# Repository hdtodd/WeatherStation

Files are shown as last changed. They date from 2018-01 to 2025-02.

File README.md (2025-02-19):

# WeatherStation/WeatherProbe v5.3
### A Raspberry Pi Weather Datalogger with </br>Arduino WeatherProbe Data Collector 

**Written by David Todd (hdtodd@gmail.com) </br>
August 2015-December 2022, Bozeman MT/Williston VT**

This project implements a weather data logging system comprised of:

1.  a Raspberry Pi program to collect meteorological data from an attached Arduino probe and 
store the data in a MySQL or sqlite3 database, or print out as simple labeled data fields, or print out or store as XML-formatted data;

2.  an Arduino Uno program to collect the meterological data from connected devices and present the data for viewing or storing.  The following devices are supported but optional.  None are required for operation -- the Uno program samples and displays data from only the devices that are attached and ignores missing devices.
  * MPL3115A altimeter/barometric pressure/temperature sensor
  * DHT22 temperature/relative humidity sensor
  * DS18-class temperature probes (zero or multiple)
  * Chronodot real-time clock
  * A 1.8" TFT color LCD display.

4.  A `Makefile`to create and install the Raspberry Pi code, including a `systemctl WeatherStation.service` file for automatic operation upon reboot;

5.  Web service support with PHP and Python code examples used with an Apache server to create web-page graphical displays using Google Charts

6.  XML DTD file and XML file parser to validate the XML data file and extract data from a validated, conforming XML file.

The Arduino is connected to the Pi or other Linux system (or Mac OSX) via USB cable.  The supplied Arduino code
is compiled on the Pi or OSX and downloaded over USB cable to the Uno (which also receives its power from the USB cable).  The WeatherStation program operating on the Pi or OSX issues commands to the Uno and receives data in return, which is then displayed to the user or stored in a database.

The included PHP and Python files offer prototypes for displaying data collected in the database (in sqlite3 format in this case) and/or presenting via an Apache2 server.

This distribution includes the source code for WeatherStation (Pi) and WeatherProbe (Arduino), Makefiles, installation guide, principles-of-operation manual, and circuit diagrams.

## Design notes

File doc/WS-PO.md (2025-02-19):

# WeatherProbe/WeatherStation</br>Principles of Operation
### H. David Todd, hdtodd@gmail.com, January, 2018

**WeatherProbe** (WP) is a program that runs on the Arduino single-board microcontroller to manage and read data from various meterological sensors.

**WeatherStation** (WS) is a program that runs on the Raspberry Pi or other Linux/Macintosh system to store that meterological data and report or present it.

They are the Arduino and Raspberry Pi software components, respectively, of a meterological station **system**. They work together to collect+display (Arudino) and record+present (Pi) meterological data from a set of sensors connected to the Arduino. This document describes the operation of that system -- how the individual components function and how they function as a system.  This PO manual may help others add components to the Arduino or functionality to the system.

## Basic Operation

### System Data Flow
The WS program on the Raspberry Pi/Linux controller manages the WP probe program on the Arduino over the USB serial port that connects the two (and powers the Arduino).  In response to commands coming over the USB serial port from WS on the Pi, the WP program performs actions, including sampling of data from its sensors, and reports the results via the USB serial connection back to the WS program if it has been commanded to do so.  

The WS program then performs the reporting action *it* was commanded to do at startup.  WS reporting options include:

1. Reporting results on the terminal controlling the WS program, in a report format with well-formatted lines and with labels for data;
1. Appending the results to a sqlite3 (default) or MySQL database;
1. Appending the results to an XML file, with appropriate XML tags in conformance with a standard DTD template for the reported data.

Operating independently, an Apache web page with PHP code can be used to access the sqlite3 or MySQL database to show current meteorologial conditions and display graphically a history (default 1 week) of temperature and pressure.  

The WP program primarily performs actions only in response to WS commands over the USB serial port.  The exception is that it periodically (default 1 minute) samples the sensors and updates the TFT display, if there is one, with current conditions.

## WeatherProbe (WP -- Arudino Code)

Arduino code has two major procedures as the main program: setup() and loop().  One-time initialization tasks are performed in setup(), and the program then enters loop(), which executes repeatedly until powerdown or restart.

### Startup
Upon upload, powerup, or restart, the WP code in the setup() procedure in the Aruindo:

1. Initializes the USB Serial port (default 9600 baud)
1. Attempts to verify active electrical connections to the TFT LCD display, the real-time-clock, and then to each of the sensors for which it has support code.  It marks as absent those devices that don't respond or don't respond correctly during this setup phase, and no further attempt is made to communicate with them.  
1. Announces its presence over the USB Serial port.
1. Enters a loop in which it continuously performs the following steps.
	1. Periodically (default 1 minute) updates weather information on the TFT display attached to the Arduino, if there is one.
	1. Looks for a command string coming over the USB serial port from the controlling device or person.
	1. In response to commands, performs the appropriate action, perhaps with text response back to the controlling device/person over the USB serial port.  The most common command operation would be `sample`, which causes WP to sample the data from each of the sensors; update the display (if there is one); and, if it has been requested to do so, report the sampled data with date-time stamp in the appropriate format (report, CSV, or XML).
	1. Repeat the loop to await further commands, while continuing to update the display periodically, if there is one. 

There is no "exit" from this code.  Once it has initialized in setup(), it enters the loop() procedure and loops until it receives a command to `restart`, at which point it simply restarts the process from step 1 above, or until the Arduino is reloaded or powered down.

### Device Support on the Arduino
WP has support for the following devices connected to the Arduino:

1. Chronodot real-time-clock, connected via I2C 
1. SainSmart 1.8" TFT LCD Display connected via SPI
1. MPL3115A2 altitude/barometer/thermometer sensor connected via Arduino pins
1. DHT22 temperature/humidity sensor connected via Arduino pins
1. DS18-class thermal sensors (up to 4, as a compile-time parameter) connected via OneWire interface to Arduino pins

If a Chronodot is not present, WP uses the internal clock of the Arduino to timestamp events.  That clock can be set by command from the controlling host over the USB serial line, which WeatherStation does when it starts up.  You'll need to do that manually if you're running WP in terminal monitor mode.

If a TFT display is present, it is used to show the date-time stamp of the latest sample, the temperatures reported on the first two DS18 temperature probes in that sampling, the relative humidity, and the **unadjusted** (see MPL below) barometric pressure in Pascals (divide by 100 to get millibars). **Barometric pressure is adjusted by the MPL3115A2 code for the altitude of the device, which is a compile-time parameter set at 40m.  It is otherwise reported from the raw data read and not adjusted for temperature or humidity.** 

If any of the other devices is absent or not sensed correctly, its absence is reported at startup over the USB serial port and it is marked absent internally.  No further attempt is made to gather data from that device, and any reported values are reported as zeros.

### WP Commands
Command processing within WP is very restricted.  The command processor does not handle line editing such as backspace character deletion or line deletion.  Input that is not recognized as a correctly-formed command is discarded: the complete line is ignored, no action is taken, and a prompt is sent over the USB serial line to indicate the commands WP is prepared to process (equivalent to having sent a "?" or "help" command).

WP commands include the following set:

*  **help** or **?** or simply **\<CR\>** (blank line)</br>returns a string over the USB serial connection to the controlling program/terminal with this list of its commands

*  **version** or **whoru**</br>returns a string identifying the version of WP and of the database for which WP is providing data (number of sensor readings and sequence of returned values must correlate with what the controlling program is expecting to store in its database)

*  **report**</br> sets WP to be in *report* mode so that subsequent `sample` commands return the timestamped, collected sensor-data string as a formatted line of labeled data

*  **csv**</br>sets WP to be in *csv* mode so that subsequent sample> commands return the timestamped, collected sensor-data string in comma-separated-variable format.  As compiled, the string has the format "(val,val,val, ...)" [see Reports, below].

*  **xmlstart**</br>causes WP to immediately return the XML header string over the USB serial port and then sets WP to be in *xml* reporting mode so that subsequent sample commands return the timestamped, collected sensor-data as XML-tagged data samples.

*  **xmlstop**</br>causes WP to immediately return the XML termination string over the USB serial port and disable xml reporting mode (reporting is disabled until another command is issued that again enables a reporting mode)

*  **sample**</br>causes WP to sample each of the known sensors and update the TFT display, if there is one.  If a reporting mode is enabled, WP also returns, over the USB serial connection to the controlling program/terminal, a string containing the date-time stamp and sampled data in the format required by the active reporting mode.</br></br>With a full set of devices, the time required for one sampling is about 1400 milliseconds (1.4 sec).

*  **settime yyyy-mn-dd hh:mm:ss** (all digits, 24-hour clock, must be formatted exactly in this way) causes WP to set the Chrondot real-time clock (if there is one) or the date-time offset for the internal Arduino interval timer, so that subsequent date-time stamps are synchronized with the host computer system.

*  **restart**</br>causes the Arduino to reboot and restart WP.

### WP Device Details

Most of the devices supported by WP are straightforward: one device, one connection, one set of data per sampling.  The exception is the DS18-class thermal sensors connected via OneWire: there may be many DS18 devices (limit of 4 as compiled).

#### **Chronodot RTC**
The Chronodot is a battery-maintained real-time-clock (RTC) that provides the date-time string used as timestamp for data records sent to the controlling program/terminal and used to display on the TFT display (if there is one).  Other RTC devices could be substituted for the Chronodot with minor changes to the code in WP.  WP assumes that the Chronodot date+time have been set before WP starts up, but the Chronodot's time can be changed with the `settime` command.  In the absence of a Chronodot, WP uses the the elapsed time since WP started as the current date+time for its date-time stamp, but, again, its base time can be set with the `settime` command.
#### **TFT Display**
The SainSmart 1.8" TFT LCD display is a color 128x160-pixel display connected via SPI interface.  The SainSmart version differs from the Adafruit version in its pinouts.  The implementation here (ST7335) uses the SainSmart pin layout for "high display speed" [[https://www.tweaking4all.com/hardware/arduino/sainsmart-arduino-color-display/]()].  WP supports the ST7735R and  ILI9163C models. The WP code is compiled to display in portrait mode but could be easily modified for landscape. The code is highly modular, with display initialization in separate section within setup() and with the display code itself in a separate procedure called from within loop().  
#### **MPL3115A2**
The MPL3115A2 is a sophisticated altitude/barometer/temperature sensor that provides the ability to read each type of sensor data independently.  Internally, the MPL reads pressure relative to an internal vacuum chamber.  It provides the ability to add a "trim" to pressure and altitude readings to compensate for any internal inaccuracies.  In setup(), WP sets that "trim" value for altitude to the difference between the MPL-measured value and a reading you might make from a GPS system, and the MPL applies that trim to any altitude reading it makes.  (The MPL code does not provide for applying pressure "trim").  Set `MY_ALTITUDE` in `WP.h` to your GPS-measured altitude, in meters, if the altitude reading is important to you and you intend to move the location of the Arduino probe with its MPL.  During sampling, WP collects altitude, pressure, and temperature from the sensor.  Using a terminal connection, put WP in `report` mode and command a `sample` to obtain the MPL readings for all three sensor values.</br>
#### **DHT22**
The DHT22 device senses temperature and relative humidity.  No settings or adjustments are possible.  During sampling, WP simply requests current values for temperature and relative humidity.  A DHT11 or DHT21 device may also be used (compile-time parameter).
#### **DS18B20**
The DS18B20 is one specific example of the OneWire DS18-class thermal sensors, and it is the device with which WP was developed.  WP *should* support the other DS18 devices (DS18S20, DS1822, DS18B20) with no code changes or recompilation required, but it should be validated with other devices before putting into production.

WP samples the two-character DS18 device label along with the temperature and reports those pairs for all connected devices to the controlling program or terminal.  WP assumes that the 2-byte Tl/Th (low/high temperature trigger settings) that are stored in DS18 EEPROM are two-character labels. (The DS18 github distribution includes a DS18 labeling program, but two bytes of the OneWire address might be used as an alternative, with minor coding changes, with some chance that labels wouldn't be unique).  Absent devices are reported as a (label,temp) pair value of ('\*\*',0.0)</br></br>By default, temperatures are measured with 10-bit precision to 0.25C (compilation parameter).</br></br>WP uses the  concurrent-sampling capability of the DS18 device: sampling is initiated concurrently across *all* DS18's, data is collected from other sensors, and then data is collected from the DS18's.  This sampling parallelism speeds up the sampling loop considerably if multiple DS18s are attached.  **As a result, the DS18's must be connected to VCC for power and cannot operate in parasitic mode.**

### WP Report Strings
WP reports sample results, if commanded to do so, as either line-printer style reports (labeled data values), csv-formatted lines (no labels), or as XML-formatted data.
#### **report**
Samples are reported as one line returned with labeled data in the format:
```
2017-09-18 16:46:59  MPL: Altitude=1650.9m Pressure=83661Pa Temp=69.8F  DHT22: Temp=70.5F @ 35% RH  DS18: IN=70.7F OU=58.1F **=0.0°F **=0.0°F 
```
DS18 labels for missing devices (in the list of 4 maximum) are given as `**` and the corresponding temperatures are `00.0`.

#### **csv**
Samples are reported as one line returned in the format "(val,val,val, ...)", with the following values in this sequence and format:

1. 'date-time' (in quotes),  in the format `'2017-09-18 16:22:05'`, suitable for reading as a string and passing to sqlite3 or MySQL
2. MPL3115A2 pressure, integer in Pascals
3. MPL3115A2 temperature reading, float in Fahrenheit
4. DHT22 temperature reading, float in Fahrenheit
5. DHT22 relative humidity reading, integer in %
6. #1 DS18 label, in the format 'xx' (in quotes)
7. #1 DS18 temperature reading, float in Fahrenheit
8. #2 DS18 label, in the format 'xx' (in quotes)
9. #2 DS18 temperature reading, float in Fahrenheit
10. #3 DS18 label, in the format 'xx' (in quotes)
11. #3 DS18 temperature reading, float in Fahrenheit
12. #4 DS18 label, in the format 'xx' (in quotes)
13. #4 DS18 temperature reading, float in Fahrenheit

#### **xml**
Sample data, in the order listed for `csv`, are reported in conformance with the XML DTD template provided with the source code (weather_data.dtd: see [Appendix](appendix-0) ).  Each sampling is marked by a \<sample\>\</sample\> begin-end pair and includes the date-time stamp and all available data in the sample, labeled and with units specified.</br>

### WP Error Processing
The WP code compiles to nearly 32K, and there is little room for additional functionality or error detection.  Attempts are made to report most errors that can WP detect, but the code is not "bullet proof".  Error and warning messages are sent over the USB serial line:

*  Informational and warning messages are preceeded by the text string "[%WP]""
*  Error messages indicating failures are preceeded by the text string "[?WP]""

A program controlling the Arduino running WP via the USB serial port can use these leading text string to identify messages that should be sent to a controlling terminal screen and/or logged to an error file.

## WeatherStation (WS -- Raspberry Pi/Linux Code)

The WS program executes on a Raspberry Pi or other Linux/Mac OSX system to collect and record data from the Arduino weather probe program, WP, over the USB serial connection between the Pi and and Arduino.

### Startup

WS starts by: 

*  processing command-line arguments (see below); 
*  verifying that it can access database files, if needed;
*  verifying that there is an Arduino connected to the Raspberry Pi with which it can communicate;
*  issuing the appropriate command to the Arduino needed to obtain data in the format that has been requested.

WS then enters a loop in which it commands the Arudino to sample data from the Arduino's sensors, receives the sample data in reply, records or prints that data as requested, then delays (default 5 minutes) before repeating.  This continues until the program is terminated.

### WS Device Support

WS was designed to connect to a single Arduino Uno via USB serial port, and it was tested only in that mode.  However, other modes of operation should be possible with relatively minor modifications or additions to the WS code:

*  Serial connection might be made by other means, such as Bluetooth Serial or WiFi or Pi/Arduino serial ports.  A wireless connection to a remote Arduino would be one of the more interesting and useful approaches and should be relatively easy to implement.
*  Multiple Arduinos could be supported from one instance of WS, or by running multiple instances, each connecting through different serial connections to different Arduinos.

### WS Commands

WS is not an interactive program.  It accepts one of three commands on the command line at startup and continues operation until terminated: 

*  `ws prt`, to indicate that WS should generate report-style printouts to the controlling terminal;
*  `ws sql`, to indicate that WS should append sample data to the database file (either sqlite3 or MySQL, depending upon compilation parameters); or 
*  `ws xml` or `ws xml filename` to indicate that WS should write data in XML format to either the controlling terminal or to the file specified as `filename`.

Any other argument on the command line, or no argument on the command line, results in a "help" response that shows what `ws` does and what it is expecting on the command line.  Any additional arguments on the command line are ignored (though redirects for `stdout` and `stderr` work as expected).

WS can be terminated with a CNTL-C (^C) from the controlling terminal or stopped with the command</br> 
`sudo systemctl stop WeatherStation.service` 
</br>if WS is operating as a `systemd` service.  As a result, the XML file is properly closed with `</sample>` under normal circumstances (but check and append that closing string to the .xml file if the system has crashed in a power failure).

### WS Databases

WS can record the date-time stamped sample data it receives from WP in either a sqlite3 (default) or MySQL database.

#### **sqlite3 Database Operations**

The sqlite3 database file name, by default in the code, is `~/WeatherData.db` so that it can be created and written to by the user during initial testing.   But in Makefile, that definition is overridden and the database filename is set to be `/var/databases/WeatherData.db` so that the system is set up for production operation.  **Note that that file will normally be protected, so either WS must run as root (or as a systemd service) or the file must be created and protections set to enable writing by the user.**

On startup, if the sqlite3 database *file* `/var/databases/WeatherData.db` doesn't exist, WS creates it.  The sqlite3 code uses a table named `Probedata` in that database file.  If it doesn't exist in the file, WS creates it with the command:

	CREATE TABLE if not exists ProbeData (date_time TEXT PRIMARY KEY,
	mpl_press INT, mpl_temp REAL, dht22_temp REAL, dht22_rh INT,
	ds18_1_lbl TEXT, ds18_1_temp REAL, ds18_2_lbl TEXT, 
	ds18_2_temp, REAL,ds18_3_lbl TEXT, ds18_3_temp REAL,
	ds18_4_lbl TEXT, ds18_4_temp REAL)

During operation, WS receives sample data from WP over the USB serial port in CSV format, with data in the order and of the types indicated in the `CREATE TABLE` command above.  It appends the received data to the sqlite3 database file with the command:

	INSERT INTO ProbeData (date_time, mpl_press, mpl_temp, dht22_temp, dht22_rh,
	ds18_1_lbl, ds18_1_temp,ds18_2_lbl, ds18_2_temp,ds18_3_lbl, ds18_3_temp,
	ds18_4_lbl, ds18_4_temp) VALUES (val, val, val, ...)
	
where the `VALUES` list is a direct copy of the string sent by WP in response to a `sample` command while in CSV mode.

The sqlite3 database file is opened and then immediately closed when recording each individual sampling, so that the file is minimally vulnerable to corruption in case of system crash.

The sqlite3 database can be examined as a normal sqlite3 database table, for example, with the command:

	$sqlite3 /var/databases/WeatherData.db
	sqlite> select * from Probedata where date_time > datetime('now', '-4 hours');
	...
	2017-09-19 08:06:57|83808|65.9|66.7|40|IN|70.3|OU|36.5|**|0.0|**|0.0
	2017-09-19 08:12:07|83813|65.6|66.4|37|IN|69.8|OU|36.0|**|0.0|**|0.0
	sqlite> .quit

WS can use a MySQL database to store its sampled data, too: see the WS-WP-install.md file for compilation instructions.

Operation of WS using a MySQL is very similar to its operation using sqlite3.  However:

*  mysql server must be running (generally done as a startup service, likely with systemctl)
*  username and password for a MySQL account that can append to the database must have been provided (edit WS.h, `make clean` and recompile with `USE_MYSQL=1 make`)
*  A `weather` database and `Probedata` table in that database must have been created under that user account with the correct field names and data types, per installation instructions.

Create the database and table with the command:
	
	$mysql -u <username here> -p
	<provide password here>
	create database weather;
	use weather;
	CREATE TABLE `ProbeData` (
  		`date_time` datetime NOT NULL,
		`mpl_press` int(6) unsigned NOT NULL,
  		`mpl_temp` float NOT NULL,
  		`dht22_temp` float NOT NULL,
  		`dht22_rh` smallint(5) unsigned NOT NULL,
  		`ds18_1_lbl` char(2) COLLATE ascii_bin DEFAULT NULL,
  		`ds18_1_temp` float DEFAULT NULL,
  		`ds18_2_lbl` char(2) COLLATE ascii_bin DEFAULT NULL,
  		`ds18_2_temp` float DEFAULT NULL,
  		`ds18_3_lbl` char(2) COLLATE ascii_bin DEFAULT NULL,
  		`ds18_3_temp` float DEFAULT NULL,
  		`ds18_4_lbl` char(2) COLLATE ascii_bin DEFAULT NULL,
  		`ds18_4_temp` float DEFAULT NULL,
  		UNIQUE KEY `date_time` (`date_time`)
		);
	show columns from ProbeData;
	quit;

In operation, WS again opens and closes database access just to record data: the connection to the database is not kept open during operation.

### WS Error Processing

There is limited error handling in WP, but WS reports the errors that occur in its side of the processing and forwards the error messages it receives from WP.  Nevertheless, the code is not "bullet proof", particularly with regard to errors that might occur in the communication between the Raspberry Pi and the Arduino.  However, the USB serial connection appears to be very stable and reliable, running for months at a time without disruption.

Similar to error messaging in WP, WS error messages have the following formats:

*  Informational and warning messages are preceeded by the text string `"[%WS]"`
*  Error messages indicating failures are preceeded by the text string `"[?WS]"`

Informational messages from WS are printed to `stdout` (the connected terminal).

Informational messages from WP and error messages from both WS and WP are printed to `stderr` by WS.  These will normally be printed to the connected terminal but can be redirected to error logging files, for example with the command:

	$./ws sql 2>wserrors.log

## Appendix:  weather_data.dtd
The listing below is the DTD template to which the WP xml output conforms.  XML output files can be validated or converted to CSV format with tools supplied with the WS/WP source code.

	<!ELEMENT samples (sample*)>
	<!ELEMENT sample (source_loc?, date_time, MPL3115A2?, DHT22?, DS18*) >
	<!ELEMENT source_loc (#PCDATA) >
	<!ELEMENT date_time (#PCDATA) >
	<!ELEMENT MPL3115A2 (mpl_alt?, mpl_press, mpl_temp) >
  		<!ELEMENT mpl_alt (#PCDATA)>
     		<!ATTLIST mpl_alt
        		alt_unit (ft|m) "m">
  		<!ELEMENT mpl_press (#PCDATA) >
     		<!ATTLIST mpl_press
				p_unit (Pa|mb|inHg) "Pa" >
  		<!ELEMENT mpl_temp (#PCDATA) >
     		<!ATTLIST mpl_temp
				t_scale (C|F|K) "F">
	<!ELEMENT DHT22 (dht_temp, dht_rh) >
   		<!ELEMENT dht_temp (#PCDATA) >
     		<!ATTLIST dht_temp
				t_scale (C|F|K) "F">
   		<!ELEMENT dht_rh (#PCDATA) >
     		<!ATTLIST dht_rh
				unit CDATA #IMPLIED>
	<!ELEMENT DS18 (ds18_lbl, ds18_temp) >
   		<!ELEMENT ds18_lbl (#PCDATA) >
   		<!ELEMENT ds18_temp (#PCDATA) >
     		<!ATTLIST ds18_temp
        		t_scale (C|F|K) "F">

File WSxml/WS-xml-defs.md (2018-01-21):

#WeatherStation XML Data Definitions

The file "weather_data.dtd" contains the definitions of the data elements that the parser is prepared to process and extract/report.  Examining the .dtd file, even without experience in xml DTD definitions, will help understand how to make changes or additions.  Here's a simple guide to the format of the .xml file.

* A conforming .xml file will begin and end with \<samples> and \</samples>
* Between those, the file may contain 0 or more elements marked with \<sample> at the beginning of the entry and \</sample> at the end.  These elements contain the data associated with one sampling of the sensors from which the probe is collecting data.
* A *sample* may contain zero or one \<source_loc> element with a text value.
* A *sample* **must** contain just one \<date_time> element with a text value.
* A *sample* may contain zero or one \<MPL3115A2> element with several required components:
	* \<mpl\_alt> or \<mpl\_alt alt\_unit=ft|m>, with a text value (note that "ft|m" means to put **either** ft or m as the unit of measure; same approach in other unit settings; in this case the measure is feet or meters, ft or m)
	* \<mpl\_press> or \<mpl\_press p\_unit=Pa|mb|inHg>, as text, units being Pascals, millibars, or inches of mercury
	* \<mpl\_temp> or \<mpl\_temp t\_scale=C|F|K>, with temperature value in text and units being Centigrade, Farenheit, or Kelvin
* A *sample* may contain zero or one \<DHT22> element, each with two required components:
	* \<dht\_temp> or \<dht\_temp t\_tscale=C|F|K> with temperature value as text
	* \<dht\_rh> as text representing the relative humidity in percent (%)
* A *sample* may contain zero or more \<DS18> elements, each with two required components:
	* \<ds18\_lbl> as text representing the two-character DS18 internal label
	* \<ds18\_temp> or \<ds18\_temp t_scale=C|F|K> with temperature value as text

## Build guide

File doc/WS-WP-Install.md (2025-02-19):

# WeatherProbe/WeatherStation</br>Installation Guide

**WeatherProbe** (WP) is a program that runs on the Arduino single-board microcontroller to read data from various meterological sensors and display current conditions on a TFT LCD display, if one is connected.  

**WeatherStation** (WS) is a program that runs on the Raspberry Pi or other Linux/Macintosh system to collect that meterological data from WP and to store and report or present it via web page. 

They are the Arduino and Raspberry Pi (or "Pi" for short) software components, respectively, of a meterological station *system*. They work together to collect+display (Arudino) and record+present (Pi) meterological data from a set of sensors connected to the Arduino. This document describes the installation of the programs and some of the compilation parameters that can be used to tailor their operation.

## Quickstart

After all of the software components have been installed and the Arduino has been connected to the Pi, a simple </br>`make; sudo make install` </br>will cause the system to begin collecting meteorological data into a sqlite3 table `ProbeData`, in the file `/var/databases/WeatherData.db`.

The system will collect data even if you have no sensors, no TFT display, and no real-time-clock connected to the Arduino!  You'll get records with a date-time stamp based on the date-time of your controlling Pi and with zeros for the rest of the data.  That's an easy way to test your software setup before you wire in sensors.  Then power-off and add the sensors, display, or real-time clock that you do have available and restart: the system will append real data to your database table.

You can check that the data are being collected with the commands:

	$sqlite3 /var/databases/WeatherData.db
	sqlite> select * from Probedata where date_time > datetime('now', '-8 hours');
	...
	2017-09-23 13:40:45|84724|67.9|67.8|34|IN|69.8|OU|48.7|**|0.0|**|0.0
	2017-09-23 13:45:55|84728|67.8|67.5|34|IN|69.8|OU|47.3|**|0.0|**|0.0
	2017-09-23 13:51:05|84722|67.9|68.0|33|IN|69.8|OU|47.7|**|0.0|**|0.0
	sqlite> .quit

If you installed the file `/var/www/index.php`, **being careful not to overwrite any current index.php file there!**, and if Apache2 is running, you can point your web browser to your host computer to see current conditions and (after a period of time to collect data) a graphical representation of the last week of temperature and barometric pressure.

Even if you don't have or don't intend to install the various devices WP is prepared to support, you'll need to download and compile in the libraries in order to compile WP.  Unavailable devices are ignored during operation.  

The installation below is tailored for a new installation of Raspbian Stretch 4.9.59 running Arduino 2.1.0.5, but WP/WS was developed on and is known to run on Jessie and earlier versions of Arduino compiler tools.  However, if you have customized the Arduino development environment from the standard IDE installation, you may need to change some configuration parameters (particulary in WP's `Makefile` -- see Appendix).  The formatted reporting uses the degree sign for temperature records: set your locale (`sudo raspi-config`) to `en_US.UTF-8` or equivalent in other languages for that to display correctly.

Here are the steps:

1. Install the Arduino IDE and `make` tools if they're not already installed: `sudo apt-get update` then `sudo apt-get install arduino arduino-core arduino-mk`.  (For more information about arduino-mk, see [http://hardwarefun.com/tutorials/compiling-arduino-sketches-using-makefile]() , particularly "Global Variables".)
1. Connect your Arduino to your Raspberry Pi with a USB cable.  Start the Arduino IDE by double-clicking the Arduino icon.  Load one of the example programs, e.g., `blink` (click through the sequence `File/Examples/01 Basics/Blink`) and test it to make sure you have a working Arduino IDE environment that can compile and link code and upload it to the Arduino.  You may need to click through the sequence `Tools/Board` and `Tools/Serial` to select your model of Arduino and your USB serial interface.
1. Set the baud rate for your USB serial interface to 9600 (else you'll need to change the speed in the WP code); 9600 seems fast enough to work with but slow enough for the serial interface to be reliable.
1. The Arduino IDE comes with a number of libraries, and you'll need the TFT and SPI libraries it provides.  You can confirm their presence by clicking through `Sketch/Import Library` and confirm that TFT and SPI are listed on the dropdown list.  If they are not already installed, install them (see [https://www.arduino.cc/en/Guide/TFT]() and [https://www.arduino.cc/en/Reference/SPI]() for details). 
1. After starting the IDE and testing your Pi-Arduino connection, the Arduino IDE should have created a `~/sketchbook` directory under your `$HOME` directory.  You need to make sure there's a personal library directory there, too:  `mkdir ~/sketchbook/libraries`.
1. You can exit the Arduino IDE now (leaving it running may cause "multiple definition" errors during later compilations).
1. Install sqlite3 and development environment: `sudo apt-get install sqlite3 libsqlite3-dev`
1. You may find it helpful to use a terminal emulation program to connect your host system to the Arduino via the USB serial line for testing purposes.  `screen` should work just fine if you have experience with it, and `make monitor` from the `.../WP` directory invokes `screen` as a terminal connection to the Arduino.  However, I had trouble getting `screen` to communicate well, and I found that `minicom` also works well for this purpose.  It's easy to install: `sudo apt-get update` then `sudo apt-get install minicom`.  But see the Appendix for configuration information, especially changing the line-termination character (which may have been my unresolved problem with `screen`).
1. Clone into `~/sketchbook` the WeatherStation package from Github: 
	* `cd ~/sketchbook`
	* `git clone https://github.com/hdtodd/WeatherStation`
1. Clone into `~/sketchbook/libraries` the various external library packages WP uses:
	* `cd /usr/share/arduino/libraries`
	* `git clone https://github.com/PaulStoffregen/OneWire`
	* `git clone https://github.com/rambo/I2C`
	* `git clone https://github.com/adafruit/DHT-sensor-library DHT`  (the IDE complains about the "-"'s if you leave off "DHT").  Then `sudo rm DHT/DHT_U*` as we don't use the universal package and it requires other libraries.
	* `git clone https://github.com/hdtodd/ChronodotI2C`
	* `git clone https://github.com/hdtodd/DS18`
	* `git clone https://github.com/hdtodd/MPL3115A2`
1. If your Arduino is something other than a Uno, `nano ~/sketchbook/WeatherStation/WP/Makefile` to edit the `Makefile` entry for `BOARD_TAG` to be your model of Arduino.  See Appendix for my functioning `Makefile`.
1. Compile and link Weatherstation and WeatherProbe programs and upload the WP code to your connected Arduino:
	* `cd ~/sketchbook/WeatherStation/src`
	* `make`
	* `make upload` </br> At this point, you can test the uploaded WP code on the Arduino by connecting to it as a terminal over the USB connection (using `screen` or `minicom`).  
1.	Now install the WS software on the Pi with the command:
	* `sudo make install`</br> The WS code will be installed in `/usr/local/bin`; the `WeatherStation.service` file will be installed, enabled, and started by `systemctl` on the Pi. If a TFT LCD display is connected to the Arduino, it will begin displaying current time and conditions when the Pi WS program collects its first sample.  The WS program will store data into `/var/databases/WeatherData.db`.
1. To avoid destroying a functioning web site, the installation procedure does not automatically install the PHP code needed by Apache2 to display accumulated weather data.  Read the `WeatherStation/src/Makefile` for instructions for manual installation.

# Detailed Instructions

## WeatherProbe (WP)

WeatherProbe is an Arduino .ino program -- essentially C++ with some constraints and with support for the Arduino devices.  WeatherStation is a C program.  Both programs are compiled and linked on the host system.  

The "host" is referenced here as a Raspberry Pi, but it could be any other Linux or Mac OSX system that offers the Arduino IDE environment.  The installation procedure in `Makefile` assumes that the host is a Pi running `systemd`.  That procedure may succeed on other Linux systems, but you'll need to perform equivalent steps manually if you're running on OSX.

The Arduino program is compiled and linked on the host to create a binary file that is executable by the Arduino.  The Arduino binary code is uploaded to the Arduino over the USB serial port **and stays resident and active until replaced, even through power cycling**.

WP supports several sensor devices, but if any are absent, WP collects and reports data from whatever sensors it *does* see.  WP will use a Chronodot real-time clock (I2C-connected, 1307-based RTC) if one is installed. But if no Chronodot is present, WP will use the Arduino's internal timer, with current date-time set by command from the controlling computer.  As a result, WP will operate and present results (with zeros for missing sensors) with no connected devices.

WP's expectations for wiring connections to various sensors are documented below and in WP.h.  That file also documents other parameters that might be changed, such as the time between updates to the TFT display or the number of DS18 thermal sensor (if you need more than 4).  If you use the Fritzing diagram for connecting sensors, TFT, and clock to the Arduino, no changes in parameters are needed.

There are no compilation options for WP with regard to sensors.  Library code for all supported sensors is compiled into the base code.  At startup, WP tests for the presence of the various sensors and uses that list to determine which ones to sample periodically.

If you want to compile and upload the WP code into the Arduino without running WeatherStation:

* `cd WeatherStation/WP`
* `make`
* `make upload; minicom`

assuming that you're using `minicom` for communication between your host Pi and the probe.  Once the code is uploaded, it will announce itself over the USB connection, inform you of any missing sensors, and then await commands over the USB port.  `?` or `help` will give a list of commands to try.  A simple example would be to type `report` and then `sample` to show you the datetime stamp and readings from any connected sensors.  WP does not support editing of command lines typed, so you can't correct typing mistakes.  Just press RETURN and start a new command line.

## Connecting the Arduino to Devices

See the Fritzing circuit diagram (`WS_Probe.fzz` or `WS_Probe.pdf`) for details, and check or edit `WP.h` to review and/or change the pin assignments on the Arduino.  Those assignments are for the Uno R3: you may need to change pin assignments on other models.

Again, missing devices are ignored by the program.  For those devices you do have, the program pin assignments are as follow:

#### Chronodot Real-Time-Clock
*  VCC to Arduino 5v
*  GND to Arduino GND
*  SCL to Arduino pin 13
*  SDA to Arduino pin 11

#### TFT pin definitions for Sainsmart 1.8" TFT SPI on the Arduino
*  TFT VCC to Arduino 5v
*  TFT GND to Arduino GND
*  TFT SCL to Arduino pin 13
*  TFT SDA to Arduino pin 11
*  TFT CS to Arduino pin 10
*  TFT RS/DC to Arduino pin 9
*  TFT Reset to Arduino pin 8
*  Arduino RESET to Arduino pin 7 (to enable TFT hardware reset on restart command)

#### DS18 pin definitions
*  VCC to Arduino 5v (We use powered rather than parasitic mode, so VCC is needed)
*  GND to Arduino GND
*  Data wire to Arduino pin 5 with 4K7 Ohm pullup to VCC 5V

#### DHT22 pin definitions
*  VCC to Arduino 5v
*  GND to Arduino GND
*  Data pin to Arduino pin 2 with 10K pullup to VCC 5v

#### MPL3115A2 pin definitions
*  VCC to Arduino 5v
*  GND to Arduino GND
*  SCL to Arduino SCL
*  SDA to Arduino SDA

## WeatherStation (WS)

The file `WS.h` documents parameters you might want to change to affect the routine operation of WS, such as the frequency of collection of data from the probe.  

The most significant compilation option for WS is the choice of database for storing the collected data. In operation, the probe can be commanded to present its results in a labeled-text report style, as a comma-separated-variable (CSV) string suitable for processing into spreadsheets or SQL databases, or in XML format.  WeatherStation commands WP to present data in CSV format and then stores the results into a SQL database.  In the distributed version of WS, you can choose to use either sqlite3 or MySQL as the database for storage.

### Database Options

WS can record the date-time stamped sample data it receives from WP in either a sqlite3 (default) or MySQL database.  

Use of sqlite3 has the advantage that WS creates the database file and table automatically (if permissions allow) and can be set up in the user's directory with no special privileges.  Use of MySQL requires that a server be installed and in operation, with appropriate permissions for the user to create a database and table, and the WS program must be compiled with MySQL hostname, username, and user password edited in the WS.h file.

The PHP code that can be used as a model for a web reporting page assumes the use of a sqlite3 database file in `/var/databases`: you'll need to modify that code if you choose to use MySQL.

#### sqlite3 Database Setup

The sqlite3 database file name, by default in the code, is `~/WeatherData.db` so that it can be created and written to by the user during initial testing.   But in Makefile, that definition is overridden and the database filename is set to be `/var/databases/WeatherData.db` so that the system is set up for production operation.  **Note that that file will normally be protected, so either WS must run as root (or as a `systemd` service) or the file must be created and protections set to enable writing by the user.**

On startup, if the sqlite3 database file `/var/databases/WeatherData.db` doesn't exist, WS creates it (if permissions allow; if this fails, check permissions and/or run as `sudo`).  The sqlite3 code uses a table named `Probedata` in that database file.  Again, if it doesn't exist in the file, WS creates it with the command:

	CREATE TABLE if not exists ProbeData (date_time TEXT PRIMARY KEY,
	mpl_press INT, mpl_temp REAL, dht22_temp REAL, dht22_rh INT,
	ds18_1_lbl TEXT, ds18_1_temp REAL, ds18_2_lbl TEXT, 
	ds18_2_temp, REAL,ds18_3_lbl TEXT, ds18_3_temp REAL,
	ds18_4_lbl TEXT, ds18_4_temp REAL)

During operation, WS receives sample data from WP over the USB serial port in CSV format, with data in the order and of the types indicated in the `CREATE TABLE` command above.  It appends the received data to the sqlite3 database file with the command:

	INSERT INTO ProbeData (date_time, mpl_press, mpl_temp, dht22_temp, dht22_rh,
	ds18_1_lbl, ds18_1_temp,ds18_2_lbl, ds18_2_temp,ds18_3_lbl, ds18_3_temp,
	ds18_4_lbl, ds18_4_temp) VALUES (val, val, val, ...)
	
where the `VALUES` list is a direct copy of the string sent by WP in response to a `sample` command while in CSV mode.

The sqlite3 database file is opened and then immediately closed when recording each individual sampling, so that the file is minimally vulnerable to corruption in case of system crash.

The sqlite3 database can be examined as a normal sqlite3 database table, for example, with the command:

	$sqlite3 /var/databases/WeatherData.db
	sqlite> select * from Probedata where date_time > datetime('now', '-4 hours');
	...
	2017-09-19 08:06:57|83808|65.9|66.7|40|IN|70.3|OU|36.5|**|0.0|**|0.0
	2017-09-19 08:12:07|83813|65.6|66.4|37|IN|69.8|OU|36.0|**|0.0|**|0.0
	sqlite> .quit

####  MySQL Database Setup

Operation of WS using a MySQL is very similar to its operation using sqlite3.  However, the setup is a bit more complicated:

*  mysql server must be running (generally done as a startup service, likely with systemctl)
*  username and password for a MySQL account that can append data to the database table must have been provided (edit WS.h, `make clean` and recompile with `USE_MYSQL=1 make`)
*  A `weather` database and `Probedata` table in that database must have been created under that user account with the correct field names and data types, per installation instructions.

Create the database and table with the command:
	
	$mysql -u <username here> -p
	<provide password here>
	create database weather;
	use weather;
	CREATE TABLE `ProbeData` (
  		`date_time` datetime NOT NULL,
		  `mpl_press` int(6) unsigned NOT NULL,
  		`mpl_temp` float NOT NULL,
  		`dht22_temp` float NOT NULL,
  		`dht22_rh` smallint(5) unsigned NOT NULL,
  		`ds18_1_lbl` char(2) COLLATE ascii_bin DEFAULT NULL,
  		`ds18_1_temp` float DEFAULT NULL,
  		`ds18_2_lbl` char(2) COLLATE ascii_bin DEFAULT NULL,
  		`ds18_2_temp` float DEFAULT NULL,
  		`ds18_3_lbl` char(2) COLLATE ascii_bin DEFAULT NULL,
  		`ds18_3_temp` float DEFAULT NULL,
  		`ds18_4_lbl` char(2) COLLATE ascii_bin DEFAULT NULL,
  		`ds18_4_temp` float DEFAULT NULL,
  		UNIQUE KEY `date_time` (`date_time`)
		);
	show columns from ProbeData;
	quit;

At this point, you'll have an empty table, `ProbeData`, in a database `weather` that has only that one table in it.

But if you've compiled WS with the MySQL username/password set and using the `make` commands `make clean; USE_MYSQL=1 make`, you're ready for operation.  

#### Both SQL Options

Whether you've chosen to run with sqlite3 or with MySQL, if you start WS with `sudo ./ws sql`, it will now append the meterological data it receives from the Arduino WP program to the sqlite3 or MySQL table using an `insert` command string in the sqlite3 example above.  And, again, you can examine that data using sqlite3 or MySQL commands similar to the sqlite3 command examples given above.

If you move your newly-compiled version of `ws` to `/usr/local/bin` and install the `systemctl` links with `make install`, your sqlite3 or MySQL version of `ws` will begin autonomous operation to collect and archive meterological data to its SQL table, and it will restart automatically when you reboot your system.

## Uninstall

You can use `make clean` from the `WeatherStation/src` directory to remove construction debris from the `make` commands.  

To remove WS from `/usr/local/bin` and stop, disable, and remove WeatherStation.service to prevent it from restarting upon a Pi reboot, use `sudo WeatherStation/src/make uninstall`.

## Author
H. David Todd, hdtodd@gmail.com, January, 2018; reformatted February, 2025

## Appendix -- minicom setup

If you use minicom to test `WP` on the Arduino from a host program, you'll need to set up the minicom configuration.  You can type `minicom -s` and set parameters as below, or you can create/edit the file `/etc/minicom/minicom.dfl`,

	/etc/minicom/minirc.dfl 
	# Machine-generated file - use "minicom -s" to change parameters.
	pu port             /dev/ttyACM0
	pu baudrate         9600
	pu rtscts           No
	pu convf            /etc/minicom/miniconv.tbl
	pu localecho        Yes
	pu addcarreturn     Yes
	
Note the use of the character translation table, miniconv.tbl.  Minicom and WP running on the Arduino have differing ideas of what terminates a line.  Rather than encounter problems with the IDE when I do need to use it, I taught minicom to change its CR line termination character to a LF character.  Since the change is in the CNTL character section of the ASCII codes, just putting that table here wouldn't be helpful.  You'll need to make that one change yourself.  Here's how:

1. On your host, `sudo minicom -s` (must be privileged to save to /etc/minicom)
1. Downarrow to the `screen and keyboard` menu entry and press enter
1. Type `O` to get to character conversion table
1. Type `E` to get to the screen with characters that start with a 0 (zero) -- these are the CNTL characters and digits
1. Type `C` to edit a character
1. Type `13` to say you want to edit character 13 (the CR character); leave input to be `13` by pressing return; change output to be `10` (the LF character) and press return
1. Type `B` to save the table and save it as `/etc/minicom/miniconv.tbl`.
1. ESC and exit from `minicom`.  You're done.

## Appendix -- arduino.mk Makefile

	$cat WP/Makefile 
	ARDUINO_LIBS  = TFT SPI I2C OneWire ChronodotI2C MPL3115A2 DHT DS18
	ARDUINO_DIR   = /usr/share/arduino
	ARDMK_DIR     = /usr/share/arduino
	AVR_TOOLS_DIR = /usr
	AVRDUDE_CONF  = /usr/share/arduino/hardware/tools/avrdude.conf
	BOARD_TAG     = uno
	include $(ARDMK_DIR)/Arduino.mk

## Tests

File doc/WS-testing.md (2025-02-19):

# Testing WS

Create the WeatherStation executable (filename 'ws') by connecting to the '.../src' directory and issuing the command `make`.  Then issuing the command `./ws ?` generates the output 

	WeatherStation v5.3: program to collect and record meteorological data
	ws <mode> where <mode> = prt | sql | xml

So `./ws prt` collects data from the Arduino weather probe at regular intervals (compile-time parameter set at 300 seconds as distributed) and generates to the controlling terminal a nicely-formatted report of the data.  And `./ws prt > myreport.rpt` generates that report to the file myreport.rpt.

Similarly, `./ws xml` generates an xml-formatted report to the terminal, and `./ws xml > live-data.xml` generates that report to the file live-data.xml.  [This package includes xml tree-parsing routines that will display the xml data elements or convert the data to comma-separated-variable, csv, format.]

The command `./ws sql` differs in that it creates (if necessary) a MySQL table or sqlite3 file and table and appends the periodic data to that file.  By default, ws compiles to use sqlite3, and the database file is stored in /var/databases/weather_data.db.  If you intend to use MySQL to store the data, you must set the database username/password in the WS.h file prior to doing the `make` that creates ws.  If you intend to use sqlite3, you must have write privileges to /var/databases or you must run ws as root, as in `sudo ./ws sql`.

You can use ^C (CNTL-C) to stop execution of ws in test mode.  It halts execution as you would expect, except that in xml mode it issues the <\\samples> text that closes the xml file correctly.  As a result, that xml file can be fed directly into the xml parsing programs to validate or extract data.

#Testing WP

If you want to compile and upload the WP code into the Arduino without running WeatherStation:

* `cd WeatherStation/WP`
* `make`
* `make upload; minicom`

assuming that you're using `minicom` for communication between your host Pi and the probe.  

Once the code is uploaded and running, it will announce itself over the USB connection, inform you of any missing sensors, and then await commands over the USB port.  `?` or `help` will give a list of commands to try.  A simple example would be to type `report` and then `sample` to show you the date-time stamp and readings from any connected sensors.  

WP does not support editing of command lines typed, so you can't correct typing mistakes.  Just press RETURN and start a new command line.

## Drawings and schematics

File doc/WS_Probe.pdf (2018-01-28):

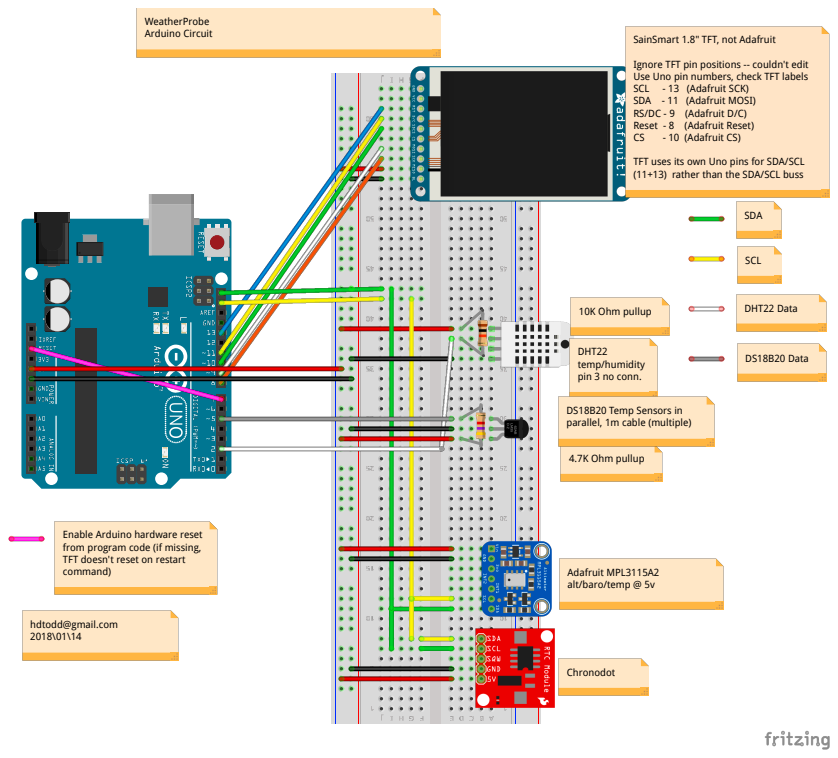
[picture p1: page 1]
DS18B20 Data; DHT22 Data; SCL; SDA; WeatherProbe Arduino Circuit; 10K Ohm pullup; - 10 (Adafruit CS); 4.7K Ohm pullup; Chronodot

SainSmart 1.8" TFT, not Adafruit

Ignore TFT pin positions -- couldn't edit
Use Uno pin numbers, check TFT labels
SCL - 13 (Adafruit SCK)
SDA - 11 (Adafruit MOSI)
RS/DC - 9 (Adafruit D/C)
Reset - 8 (Adafruit Reset)

TFT uses its own Uno pins for SDA/SCL
(11+13) rather than the SDA/SCL buss

DHT22
temp/humidity
pin 3 no conn.

DS18B20 Temp Sensors in
parallel, 1m cable (multiple)

Enable Arduino hardware reset
from program code (if missing,
TFT doesn't reset on restart
command)

Adafruit MPL3115A2
alt/baro/temp @ 5v

hdtodd@gmail.com

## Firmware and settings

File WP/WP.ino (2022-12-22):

/* Weather_Probe V5.3
 
   In response to queries from a USB-connected Raspberry Pi, gather
   and report back meterological  data using the DS18B20 temp sensor,
   the DHT22 humidity/temp sensor, and the MPL3115A2 
   altitude/pressure/temperature sensor.  Date, time and temperature
   values are also collected from a Chronodot RTC.

 MPL3115A2 and Chronodot communications handled by the I2C library of Wayne Truchsess
 to avoid the lost bits and unsynchronized byte frames that were common when
 using the Wire library, apparently caused by the "repeat-start" method used by 
 Freescale but not supported well by Wire.  Highly stable with I2C library.
 MPL3115A2 and Chronodot device handlers rewritten to use the I2C library.
 
 MPL3115A code based on code by: A.Weiss, 7/17/2012, changes by 
 Nathan Seidle Sept 23rd, 2013 (SparkFun), and Adafruit's TFT Library

   The OneWire library is used for communication with the DS18B20 
   sensor.  MPL3115A2 and Chronodot communications handled by the 
   I2C library of Wayne Truchsess to avoid the lost bits and 
   unsynchronized byte frames that were common when using the 
   Wire library, apparently caused by the "repeat-start" method used
   by Freescale but not supported well by Wire.  Highly stable with 
   the I2C library.

   The MPL3115A2 and Chronodot device handlers were rewritten to use the
   I2C library.  The MPL3115A2 library is based on the MPLhelp3115A code
   by A.Weiss, 7/17/2012, with changes by Nathan Seidle Sept 23rd, 
   2013 (SparkFun).

   For the ST7735-based TFT display, Adafruit's TFT Library is used.

   Code and revisions to this program by HDTodd:

  V5.3, 2022\12\22
    Adjust pressure to be sea-level pressure using calibration 
    correction and altitude correction.  Code changes in WP.ino.
    See WP.h to adjust parameters for other sensors and locations
    other than Williston VT.

  V5.2, 2018\02\20
    Add samplingLED to turn on LED (default pin 12) when WP is sampling sensors

  V5.1, 2018\01\17
    Add support for setting and getting time from Arduino from controller

  V5, 2017\08\31
     Add support for DS18B20 Onewire-based temp multi-probes
     OneWire library used for communication with the DS18B20 sensors
       http://www.pjrc.com/teensy/td_libs_OneWire.html
       http://milesburton.com/Dallas_Temperature_Control_Library
     See associated app tools to label sensors and characterize the DS18B20's
 
  V4.3 2017\06\27
     Major restructuring of main Probe loop to simplify structure
     and reduce code size to make room for DS18 addition 

  V4.2  2017\06
     Finish modularizing code, verify correct operation, eliminate
     compilation warning messages, reduce code size as much as 
     possible, prepare for DS18 incorporation

  V4.1  2016\08\10
     Revised Feb-Aug 2016 to modularize code

  V4, 2016\02\17
     Add "WhoRU" command response to identify WeatherProbe software
     Restructure and extend WP code in V4:
       -  Modularize code so program flow is easier to understand 
          and modify
       -  Modify code so that it fails gracefully if device absent
       -  Incorporate code to collect and report data from DS18B20
          One-Wire connected thermal sensors

  V3, 2015\10
     Reliable working version with CSV, XML, and report output modes
     functioning
  V3.1, 2016\01\26
     Revise to use pseudo-clock (based on millis() ) in revised 
     ChronodotI2C code if hardware Chronodot clock not installed.  
     Use internal clock for time-stamping data if a RTC device isn't
     installed
  V2, 2015\08
     Prototyping of basic probe code with just clock and DHT22 
     supported

----------------------------------------------------------------------
Setup and Code Management

 Uses the F() macro to move strings to PROGMEN rather than use from SRAM; see
    https://learn.adafruit.com/memories-of-an-arduino/optimizing-sram
 
   License: This code is public domain but you buy those original
     authors (Weiss, Seidle) a beer if you use this and meet them 
     someday (Beerware license).
 
   Edit .h file if you change connection pins!!!
 
   Hardware Connections to MPL3115A2 (Breakoutboard to Arduino):
     -VCC = 3.3V
     -SDA = A4    Add 330 ohm resistor in series if using 5v VCC
     -SCL = A5    Add 330 ohm resistor in series if using 5v VCC
     -GND = GND
     -INT pins can be left unconnected for this demo
 
   Hardware connections to the DS18B20
     -VCC (red)     = 3.3V DOES NOT USE PARASITIC DATA/POWER 
     -GND (black)   = GND 
     -DATA (yellow) = A5 with 4K7 ohm pullup resistor to VCC
 
   Usage:
     - Serial terminal at 9600bps (edit setup() to change speed)
     - Times various sensor measurements
     - Examines status flags used to poll device for data ready

   Author:
     H. D Todd, Williston VT/Bozeman MT
     hdtodd@gmail.com
     2015-2017
 */

#include <stdio.h>
#include <TFT.h>                   // TFT display using SPI comm
#include <SPI.h>
#include <I2C.h>                   // for IIC communication
#include "OneWire.h"
#include "ChronodotI2C.h"          // Real-Time Clock
#include "MPL3115A2.h"             // MPL3115 alt/baro/temp
#include "DHT.h"                   // DHT22 temp/humidity
#include "DS18.h"		   // DS18B20 temp sensors
#include "WP.h"                   // and our own defs of pins etc
                                    
Chronodot  RTC;                    // Define the Chronodot clock
RTC_Millis Timer;                  //   and software clock in case no Chronodot
MPL3115A2  baro;		   // Barometer/altimeter/thermometer
TFT TFTscreen = TFT(cs, dc, rst);  // create an instance of the TFT
DHT myDHT22(DHTPIN, DHTTYPE);      // create the temp/RH object
DS18 ds18(oneWirePin);             // Create the DS18 object.

long startTime;
rptModes   rptMode=report;         // default to report mode
dsInfo dsList[DSMAX+1];		   // max number of DS devices + loop guard

boolean    haveRTC, haveDHT22, haveMPL3115, haveDS18, haveTFT;
int	   dsCount;
uint8_t    dsResMode=1;		   // use 10-bit for precision
void getTime(char dtString[20]);
void setTime(char *dtS);
void readSensors(struct recordValues *rec);
void updateTFT(struct recordValues *rec);
void reportOut(rptModes rptMode, struct recordValues *rec);
tftTYPE findTFT(void);
uint32_t readwrite8(uint8_t tftCmd, uint8_t tftBits, uint8_t TFTDummy);
/* following booleans cause sampling to be triggered on the
   first pass through the main loop */
boolean    haveDisplayed=false, gotCmd=false, timedOut=true;

/*
 * setup() procedure
 -----------------------------------------------------------------
*/
void setup(void) {
  // set up to use Arduino RESET line in case it's wired
  // if not wired for hardware reset, Arduino won't see TFT on restart
  // See ref at http://www.instructables.com/id/two-ways-to-reset-arduino-in-software/
  digitalWrite(ardRESET, HIGH);
  delay(200);
  pinMode(ardRESET, OUTPUT);
  pinMode(samplingLED, OUTPUT);
  digitalWrite(samplingLED, LOW);

  // start serial port
  Serial.begin(9600,SERIAL_8N1);
  Serial.println("WP starting");
/*
  Do not reorder the following module startup sequences.  Some
  signal and timing dependences will cause component failures.
  I2C always before clock.
  The TFT device is particularly sensitive to timing and sequence.
*/
  haveTFT = ! ( findTFT() == tftMISSING );
  if (!haveTFT) Serial.println("[%WP] TFT not found");
  if (haveTFT) {
    TFTscreen.begin();
    /*
     * clear the screen with a black background & set orientation
     * 0 ==> 0 Deg rotation, 1==> 90 Deg rot, etc.
     */
    TFTscreen.background(TFT_BLACK);
    TFTscreen.setRotation(0);
    /*
     * set the font color to white & set the font size
     */
    TFTscreen.stroke(TFT_WHITE);
    TFTscreen.setTextSize(2);
  }; 

  // The following line sets the RTC to the date & time this sketch was compiled
  // uncomment if Chronodot hasn't been set previously
  // RTC.adjust(DateTime(__DATE__, __TIME__));

  // I2c before Chronodot
  I2c.begin();                      // join i2c bus
  I2c.setSpeed(1);                  // go fast
  RTC.begin();                      // init the clock
  haveRTC = RTC.isrunning();
  if (!haveRTC ) {
    Serial.println(F("[%WP] RTC is NOT connected!  Emulating clock."));
    Timer.adjust(DateTime((char *)__DATE__, (char *)__TIME__));  // set pseudo clock
  };

  baro = MPL3115A2();               // create barometer
  haveMPL3115 = baro.begin();	    // is MPL3115 device there?
  if ( haveMPL3115 ) {              // yes, set parameters
    baro.setOversampleRate(sampleRate);
//    baro.setAltitude(MY_ALTITUDE);  // Set with known altitude
  } else {
    Serial.println(F("[%WP] MPL3115A2 is NOT connected!"));
  };
                                 
  myDHT22.begin();                 // Create temp/humidity sensor
  delay(2000);                     // Specs require at least at 2 sec 
                                   // delay before first reading  
  haveDHT22 = myDHT22.read();      // see if it's there/operating
  if ( !haveDHT22 ) Serial.println(F("[%WP] DHT22 is NOT connected!"));  

  haveDS18 = ds18.begin();
  if ( !haveDS18 ) {
     Serial.println(F("[%WP] DS18 probes NOT connected!")); }
   else {
     ds18.reset();
     ds18.reset_search();
     delay(dsResetTime);
     // Scan for address of next device on OneWire
     for (dsCount=0; (dsCount<DSMAX) && ds18.search(dsList[dsCount].addr) ; dsCount++) {
       // We have a device & space to store its info; verify it and record it or discount it
       // We'll discount if CRC isn't valid or if it's not a know DS18 type

       // First, confirm CRC of address to make sure we're getting valid data
       boolean validCRC=  (ds18.crc8(dsList[dsCount].addr, 7) == dsList[dsCount].addr[7]);

       // Confirm that it's a DS18 device and assign type
       dsList[dsCount].type = ds18.idDS(dsList[dsCount].addr[0]);

       // Ignore responses with invalid CRCs or from devices we don't know
       if ( !validCRC ||
            ( dsList[dsCount].type == DSNull  ) ||
            ( dsList[dsCount].type == DSUnkwn ) )
           dsList[dsCount--].alive = false;
         else
          dsList[dsCount].alive = true;
       };	  // end for (search for DS18 devices)

  // At this point, we've identified the DS18 devices, identified their types, and
  //   recorded their information
  // Make sure we have at least SOME DS18 devices and that we didn't have too many

  if (dsCount<=0) {
    Serial.println("[%WP] No valid DS18-class devices found!");
    haveDS18 = false;
  };
  if (dsCount>=DSMAX) {
    Serial.println(F("[%WP] Number of OneWire devices exceeds internal storage limit"));
    Serial.print(  F("             Only "));
    Serial.print(--dsCount);
    Serial.print(F(" DS18 devices will be sampled."));
  };

  // set the precisions for DS18 probe samplings
  for (int dev=0; dev<dsCount; dev++) {
    ds18.reset();
    ds18.select(dsList[dev].addr);
    ds18.setPrecision(dsList[dev].addr,dsResMode);
    };

  // clean up after DS18 device search and setup
  ds18.reset_search();          // reset search,
  delay(dsResetTime);           // must wait at least 250 msec for reset search
  };			        // end else (!haveDS)

  /* And finally, announce ourselves in an XML-compatible manner
   * Note that an automated data collector should be prepared to clear 
   * the input buffer in order to ignore extraneous inputs like this
   */
  Serial.println(F("<!-- Arduino-Based Weather Probe for Raspberry Pi -->"));   
  while (Serial.available() > 0) Serial.read();   // clear incoming buffer

}  				 // end setup()

/*
 * loop() procedure
 -----------------------------------------------------------------
 * In main loop, make a first pass to collect data from the sensors
 * and display it on the TFT.  Then wait for at most 'UPDATE_DELAY' 
 * msec, waiting for a command from the Pi.  If we get a command, 
 * act on it.  If it causes a data sampling (and TFT update), reset 
 * the timer.  It it doesn't cause a data sampling, go back into the 
 * loop to wait for the timer expiration.  If the timer expires 
 * (with no command having come in), just go through the loop to 
 * collect sensor data and update the TFT
 */
void loop(void) { 
  long marker;
  DateTime now;
  int cmd=noCmd;
  boolean foundCmd=false;
  String cmdString;
  struct recordValues rec;
  
/* Note start time for loop metrics and for timeout monitoring */
  marker = startTime = millis();   // Time the loop & note time for elapsed

/* Now wait for either timeout or a typed-in command */
  while (!timedOut && !gotCmd) {
    while (!(gotCmd=(Serial.available() > 0))    // get response or timeout
           && !(timedOut=((millis()-marker) > UPDATE_DELAY))) delay(1);  

/* Something happened -- timeout or command received? */
  if (gotCmd) {                       //  we received a command: get and parse it
    cmdString = Serial.readStringUntil('\n');
    cmdString.toLowerCase();
    foundCmd = false;
    cmd = (int)vers-1;
    do
      foundCmd = (cmdString.startsWith(cmdNames[++cmd]));
      while ( !foundCmd && cmd<noCmd );
    } else {
      cmd = csample;                 // timedOut almost like sample
    };				     // end if (gotCmd) ... else
  };				     // end while (!gotCmd && !timedOut)		

/* Process that command */
  switch (cmd) {
    case vers:
    case cwhoru:
      Serial.println(Vers);
      break;
    case csample:
      readSensors(&rec);
      updateTFT(&rec);
      if (!timedOut) reportOut(rptMode, &rec);
      break;                       // leave cmd/delay loop and go do sample
    case creport:
      rptMode = report;
      break;
    case ccsv:
      rptMode = csv;
      break;
    case cxmlstart:
      rptMode = xml;
      Serial.println(F("<?xml version=\"1.0\" ?>"));
      Serial.println(F("<!DOCTYPE samples SYSTEM \"weather_data.dtd\">"));
      Serial.println(F("<samples>"));
      break;
    case cxmlstop:
      rptMode = none;
      Serial.println(F("</samples>"));
      break;
    case csettime:
      setTime((char *) (cmdString.substring(8)).c_str());
      break;
    case crestart:
      // See http://www.instructables.com/id/two-ways-to-reset-arduino-in-software/
      digitalWrite(ardRESET, LOW);			   // [hdt] try hard reset first
      restartFunc();	     				   // if not wired, do soft & let TFT fail
      Serial.println(F("[?WP] Hard and soft reset attempts failed!"));
      break;
    default:
    case chelp:
    case noCmd:
      Serial.print(F("Command, one of: "));
      for (cmd=(int)vers; cmd < (int)noCmd; cmd++) { 
        Serial.print(cmdNames[cmd]); Serial.print(" | "); };
      Serial.println("?");
      break;
    };				// end switch(cmd)

/* Reset trigger conditions and go to next loop iteration */
  timedOut = gotCmd = false;
}; // end loop()

void reportOut(rptModes rptMode, struct recordValues *rec) {

  switch (rptMode) {
  case none:
    return;
    break;
  case report:                 // report-style printout
    Serial.print(rec->cd.dt);
    Serial.print(F("  MPL: Altitude="));
    Serial.print(rec->mpl.alt, 1);
    Serial.print(F("m"));
    Serial.print(F(" Pressure="));
    Serial.print(rec->mpl.press, 0);
    Serial.print(F("Pa"));
    Serial.print(F(" Temp="));
    Serial.print(rec->mpl.tempf, 1);
    Serial.print(F("\xB0""F"));
    Serial.print(F("  DHT22: Temp="));
    Serial.print(rec->dht.tempf,1);
    Serial.print(F("\xb0""F @ "));
    Serial.print(rec->dht.rh,0);
    Serial.print(F("% RH"));
    Serial.print(F("  DS18: "));
    for (int dev=0; dev<DSMAX; dev++) {
      Serial.print(rec->ds18.label[dev]);
      Serial.write('=');
      Serial.print(rec->ds18.tempf[dev],1);
      Serial.print(F("\xB0""F "));
      };
    Serial.println();
    break;

  case csv:                    // CSV printout for database or spreadsheet
    Serial.print("(\'");       
    Serial.print(rec->cd.dt);          Serial.print("\',");
    Serial.print(rec->mpl.press,0);    Serial.print(",");
    Serial.print(rec->mpl.tempf,1);    Serial.print(",");
    Serial.print(rec->dht.tempf,1);    Serial.print(",");
    Serial.print(rec->dht.rh,0);       
    for (int dev=0; dev<dsCount; dev++) {
      Serial.print(",\'"); Serial.print(rec->ds18.label[dev]);
      Serial.print("\',"); Serial.print(rec->ds18.tempf[dev],1);
      };
    // If not DSMAX devices, output dummy 
    for (int dev=dsCount; dev<DSMAX; dev++) {
      Serial.print(","); Serial.print("\'**\',00.0");
      };
    Serial.println(")");
    break;
         
  case xml:                    // encapsulate data sample in XML wrapper
    Serial.println(F("<sample>"));
    Serial.print(F("<date_time>'"));
    Serial.print(rec->cd.dt);
    Serial.println(F("'</date_time>"));
    Serial.println(F("<MPL3115A2>"));
    Serial.print(F("<mpl_press p_unit=\"Pa\">"));
    Serial.print(rec->mpl.press,0); 
    Serial.println(F("</mpl_press>"));
    Serial.print(F("<mpl_temp t_scale=\"F\">"));
    Serial.print(rec->mpl.tempf,1);
    Serial.println(F("</mpl_temp>"));
    Serial.println(F("</MPL3115A2>"));  
    Serial.println(F("<DHT22>"));    
    Serial.print(F("<dht_temp t_scale=\"F\">"));
    Serial.print(rec->dht.tempf,1);
    Serial.println(F("</dht_temp>"));
    Serial.print(F("<dht_rh unit=\"\%\">"));
    Serial.print(rec->dht.rh,0);
    Serial.println(F("</dht_rh>")); 
    Serial.println(F("</DHT22>"));       
 
    for (int dev=0; dev<dsCount; dev++) {
      Serial.println(F("<DS18>"));
      Serial.print(F("<ds18_lbl>")); 
      Serial.print(rec->ds18.label[dev]);
      Serial.println(F("</ds18_lbl>"));
      Serial.print(F("<ds18_temp t_scale=\"F\">"));
      Serial.print(rec->ds18.tempf[dev],1);
      Serial.println(F("</ds18_temp>"));
      Serial.println(F("</DS18>"));
      };
    // If not DSMAX devices, output dummy 
    for (int dev=dsCount; dev<DSMAX; dev++) {
      Serial.println(F("<DS18>\n<ds18_lbl>**</ds18_lbl>\n<ds18_temp t_scale=\"F\">00.0</ds18_temp>\n</DS18>"));
      };


    Serial.println(F("</sample>"));      
    break;
  };				// end switch (rptMode)
};				// end void reportOut()

// sets the Chronodot or RTC clock based on the supplied 20-character date-time string
// input string must be formatted as "yyyy-mm-dd hh:mm:ss"
void setTime(char *dtS) {
  uint8_t yy,mn,dd,hh,mm,ss;
  yy = xconv2d(dtS+2);
  mn = xconv2d(dtS+5);
  dd = xconv2d(dtS+8);
  hh = xconv2d(dtS+11);
  mm = xconv2d(dtS+14);
  ss = xconv2d(dtS+17);
  if (yy*mn*dd==0) { 
    Serial.print(F("[%WP] setTime called with yy*mon*dd = 0 and input string = '"));
    Serial.print(dtS);
    Serial.println("'");
    }
  else
    if ( haveRTC )
      RTC.adjust(DateTime(yy,mn,dd,hh,mm,ss,0.0,0.0));
    else
      Timer.adjust(DateTime(yy,mn,dd,hh,mm,ss,0.0,0.0));
}

// returns the current date & time, as recorded by the Chronodot or Arduino RTC, 
// as a null-terminated, 20-character date-time string in the format "yyyy-mm-dd hh:mm:ss"
void getTime(char dtString[20]) {
  DateTime now;
  now = haveRTC ? RTC.now() : Timer.now();
  sprintf(dtString, "%4d-%02d-%02d %02d:%02d:%02d%c", now.year(), now.month(), now.day(),
      now.hour(),now.minute(), now.second(), '\0' );;
};

void readSensors(struct recordValues *rec) {
  uint8_t data[9];

  digitalWrite(samplingLED, HIGH);	    // visual sign that we're sampling
  // time stamp this record
  getTime(rec->cd.dt);

  // if we have DS18s, start reading temps now, in parallel
  if ( haveDS18 ) ds18.readAllTemps();
  
  if ( haveMPL3115 ) {
  // v5.3: adjust pressure for calibration and altitude
    rec->mpl.press = baro.readPressure()+MY_ELEV_CORR+MY_CALIB_CORR;   // Get MPL3115A2 data
    rec->mpl.alt   = baro.readAltitude();
    rec->mpl.tempf  = baro.readTempF();
  }
  else {
    rec->mpl.press = 0.0;
    rec->mpl.alt   = 0.0;
    rec->mpl.tempf  = 0.0;
  };
  
  if ( haveDHT22 ) {
    rec->dht.tempf = myDHT22.readTemperature(true); // Get DHT22 data with temp in Fahrenheit
    rec->dht.rh    = myDHT22.readHumidity();
  } else {
    rec->dht.tempf = 0.0;
    rec->dht.rh    = 0.0;
  };

// Get data for the DS18's we have, zero the rest
  if ( haveDS18 ) {
    ds18.waitForTemps(convDelay[(int)dsResMode]);
    for (int dev=0; dev<dsCount; dev++) {
      rec->ds18.tempf[dev] = CtoF(ds18.getTemperature(dsList[dev].addr, data, false));
      rec->ds18.label[dev][0] = data[2];
      rec->ds18.label[dev][1] = data[3];
      rec->ds18.label[dev][2] = 0x00;
    };
  };
  for (int dev=dsCount; dev<DSMAX; dev++) {
    rec->ds18.tempf[dev] = 0.0;
    rec->ds18.label[dev][0] = rec->ds18.label[dev][1] = '*';
    rec->ds18.label[dev][2] = 0x00;
  };
  digitalWrite(samplingLED, LOW);
};                            // end readSensors
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

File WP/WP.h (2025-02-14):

// Definitions used by the Arduino Uno Weather_Probe code, WS.ino
//
#define Vers "WP5.3 DB3.0"    // <Code-version> <Database-version>
                              // DB version may be used to create
                              // sqlite3 DB CREATE/INSERT strings,
                              // so be sure to update its version
                              // number if you change the DB
                              // structure below

typedef enum rptMode {none=0, report, csv, xml} rptModes;
typedef enum cmdTypes {vers=0, csample, creport, ccsv, cxmlstart, 
		       cxmlstop, cwhoru, chelp, csettime, crestart,  noCmd} cmds;
static const String cmdNames[] = {"version","sample", "report", "csv", 
				  "xmlstart", "xmlstop", "whoru", "help",
				  "settime", "restart", "unrecognized"};

// Chronodot RTC
                              // VCC to Uno 5v, GND to Uno GND
                              // SCL to Uno pin 13
                              // SDA to Uno pin 11

// TFT pin definitions and parameters for Sainsmart 1.8" TFT SPI on the Uno
#define ardRESET 7            // wire Arduino RESET pin to Arduino pin 7 to allow TFT reset on restart
                              // TAKE CARE in picking a pin: 12 didn't work.
                              // Even now, uploading may not sync correctly with 7 tied to reset
                              // VCC to Uno 5v, GND to Uno GND
                              // SCL to Uno pin 13
                              // SDA to Uno pin 11
#define cs  10                // CS to pin 10
#define dc   9                // RS/DC to pin 9
#define rst  8                // Reset to pin 8
#define UPDATE_DELAY 60000    // update TFT every 60 sec if no Pi command comes in
#define TFT_BLACK 0,0,0
#define TFT_WHITE 255,255,255
typedef enum tftTYPE { tftMISSING=0, tftST7735R, tftILI9163C } tftTYPE; // see Prentice
tftTYPE  findTFT(void);

// DS18 pin definitions and parameters
                              // We use powered rather than parasitic mode
                              // VCC to Uno 5v, GND to Uno GND
                              // Connect the DS18 data wire to Uno pin 5
                              //  with 4K7 Ohm pullup to VCC 5V
#define dsResetTime 250       // delay time req'd after search reset in msec
#define DSMAX 4               // max number of devices we're prepared to handle
#define oneWirePin 5          // We'll use Uno pin 5 for OneWire connections to DS18B20

// DHT22 pin definitions and parameters
                              // VCC to Uno 5v, GND to Uno GND
#define DHTPIN 2              // Data pin to Uno pin 2
                              // connect a 4K7-10K pull-up resistor between VCC 5v and data pin
#define DHTTYPE DHT22         // the model of our sensor -- could be DHT11 or DHT21

#define samplingLED 12        // pin to put a current-limited LED to be signaled during sampling

// MPL3115A2 pin definitions and parameters
                              // VCC to Uno 5v, GND to Uno GND
                              // SCL to Uno SCL
                              // SDA to Uno SDA
uint8_t sampleRate=S_128;     // Sample 128 times for each MPL3115A2 reading
#define MY_ALTITUDE 169       // Set this to your actual GPS-verified altitude in meters
                              // if you want altitude readings to be corrected
                              // Bozeman, MT = 1520m, Williston VT = 169m
#define MY_ELEV_CORR 18.0*100 // millibars-> Pascals, From Table 2,
                              //   https://www.starpath.com/downloads/calibration_procedure.pdf
#define MY_CALIB_CORR 3.5*100 // millibars-> Pascals, calibrated for my MPL: replace with yours
#define FT_PER_METER 3.28084  // conversion

void     (* restartFunc) (void) = 0;  // declare restart function at address 0
uint32_t readwrite8(uint8_t cmd, uint8_t bits, uint8_t dummy);

struct fieldDesc {
  const char *fieldName; const char *fieldAttributes; };
struct fieldDesc fieldList[] = {
  {"date_time", "TEXT PRIMARY KEY"},
  {"mpl_press", "INT"},
  {"mpl_temp",  "REAL"},
  {"dht22_temp","REAL"},
  {"dht22_rh",  "INT"},
  NULL,        NULL };

struct mplReadings {
  float alt;
  float press;
  float tempf;
};

struct dhtReadings {
  float tempf;
  float rh;
};

struct cdReadings {
  char  dt[20];
  float tempf;
};

struct dsReadings {
  char label[DSMAX][3];
  float tempf[DSMAX];
};

struct recordValues {
  struct cdReadings  cd;
  struct mplReadings mpl;
  struct dhtReadings dht;
  struct dsReadings ds18;
    };

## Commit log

2018-01-22 Editing documentation
    [WS_Probe.fzz]
2018-01-28 document pins
    [WS_Probe.fzz]
2018-03-05 Update version to 5.2, fix typos
    [WP.h, WP.ino]
2022-12-22 V5.3: correct barometric pressure reading to sea level
    [WP.h, WP.ino]
2023-09-18 Edit web page for current temp to 1 decimal point
